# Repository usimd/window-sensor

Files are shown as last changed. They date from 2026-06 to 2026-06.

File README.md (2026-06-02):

# BLE window sensor for Homeassistant







BLE window/door sensor built around the u-blox NORA-B226 (nRF54L10). Broadcasts open/closed/tilt state via BTHome v2 non-connectable advertising. MCUboot OTA-capable.

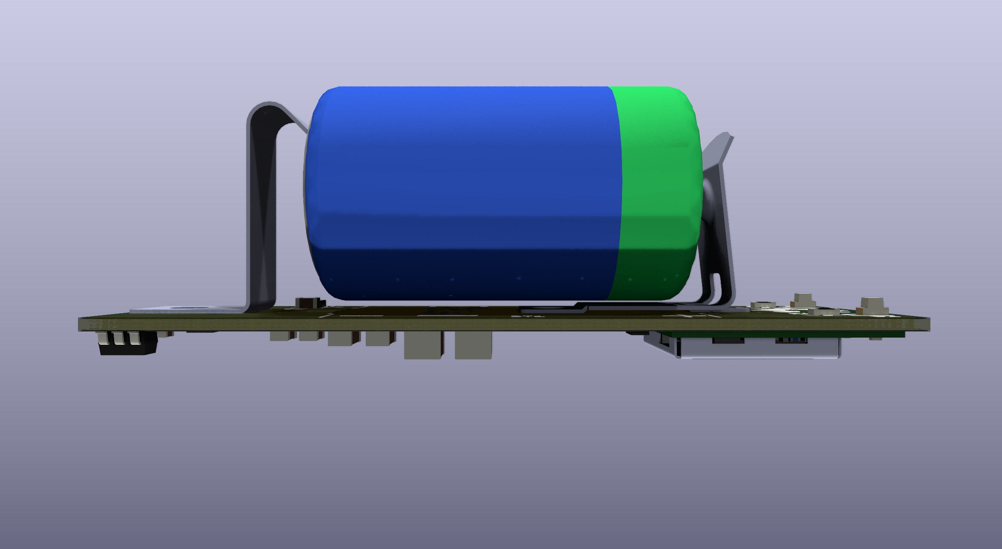
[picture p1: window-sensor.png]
Rendered PCB


## Hardware

- **MCU**: nRF54L10 (Cortex-M33, 1 MiB RRAM, 192 KB RAM) in u-blox NORA-B226-00B module
- **Sensor**: TMAG5273 3D Hall-effect sensor for contactless magnet detection
- **Power**: CR14250 (½AA) lithium cell, target multi-year battery life
- **Enclosure**: 3D-printed case with magnet holder (FreeCAD, `case/`)

## Firmware

Rust + Embassy async runtime, BLE via nrf-sdc + trouble-host.

- Non-connectable BTHome v2 advertising (open / closed / tilt)
- MCUboot bootloader with ed25519-signed OTA images
- Host-side unit tests for classifier and gesture logic

## Repository Structure

| Path | Description |
|---|---|
| `*.kicad_*` | KiCad 10 schematic, PCB, and project files |
| `lib/` | Local symbol/footprint libraries and 3D models |
| `firmware/` | Rust firmware (Embassy, BLE, MCUboot support) |
| `firmware/mcuboot/` | MCUboot config and partition overlay |
| `case/` | FreeCAD enclosure design and 3MF exports |
| `scripts/` | BLE scanner and dev utilities |
| `sim/` | Magnetic simulation data |

## Building

```bash
# Install toolchain
rustup target add thumbv8m.main-none-eabihf
cargo install just cargo-binutils

# Build, lint, test
just ci

# Flash (requires probe-rs + debug probe)
just run
```

## License

Dual-licensed: hardware under CERN-OHL-W-2.0, firmware under Apache-2.0. See [`LICENSE`](LICENSE).

## AISLER discount

In case you want to build this (or any other) project at AISLER, here's a 10€ discount code for you: `MakeInEurope-ZDCTN`.

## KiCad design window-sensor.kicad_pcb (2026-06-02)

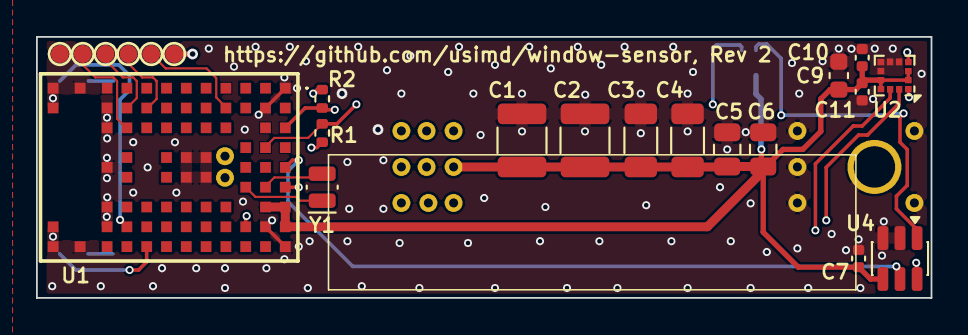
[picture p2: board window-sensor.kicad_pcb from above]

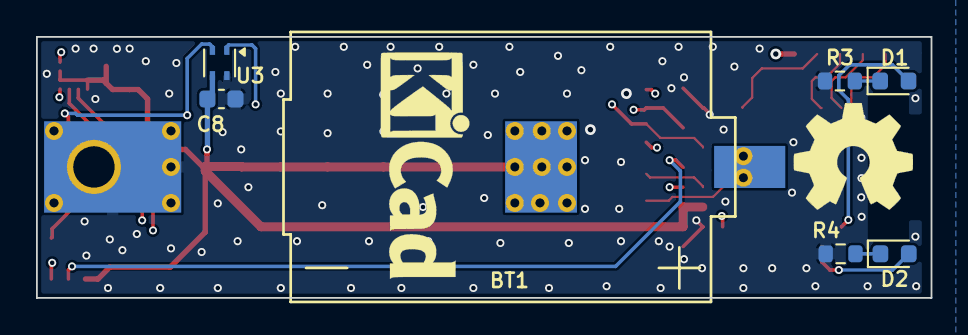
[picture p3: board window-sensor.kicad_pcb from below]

Board: 4 copper layers, 49.7 x 14.5 mm, 24 parts (7 on the bottom side), 17 nets.

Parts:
BT1: 1/2 AA LiSOCl2 3.6V 1200mAh; Battery_0.5AA_Keystone_557_5331
C1, C2: 47uF 10V X7R; C_1210_3225Metric
C3, C4: 22uF 10V X7R; C_1206_3216Metric
C5, C6: 10uF 10V X7R; C_0805_2012Metric
C7, C10, C11: 1uF; C_0402_1005Metric
C8: 1uF; C_0603_1608Metric
C9: 10uF; C_0603_1608Metric
D1: Blue; LED_0603_1608Metric
D2: Red; LED_0603_1608Metric
J1: Conn_01x06; Conn_01x06_PogoPins_1.27mm
R1, R2: 16.9k; R_0402_1005Metric
R3: 60.4; R_0603_1608Metric
R4: 160; R_0603_1608Metric
U1: NORA-B216-00B; NORAB22600B
U2: LIS2DTW12TR; LGA-12_2x2mm_P0.5mm
U3: SHT4x; Sensirion_DFN-4_1.5x1.5mm_P0.8mm_SHT4x_NoCentralPad
U4: TMAG5273; SOT-23-6
Y1: 32.768kHz; Crystal_SMD_MicroCrystal_CC8V-T1A-2Pin_2.0x1.2mm

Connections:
+BATT: BT1.1 (+), C1.1, C2.1, C3.1, C4.1, C5.1, C6.1, C7.1, C8.1, C9.1, C10.1, C11.1, J1.1, R1.1, R2.1, U1.A7 (VCC), U1.A8 (VCC_2), U1.B7 (VCC_3), U2.2 (~CS), U2.3 (SA0/SDO), U2.9 (Vdd), U2.10 (Vdd_IO), U3.3 (VDD), U4.4 (VCC)
/HALL: U1.A5 (GPIO_1), U4.5 (~INT)
/MEMS_INT1: U1.A6 (GPIO_2), U2.12 (INT1)
/MEMS_INT2: U1.C8 (GPIO_3), U2.11 (INT2)
/SCL: R2.2, U1.A3 (I2C_SCL), U2.1 (SCL/SPC), U3.2 (SCL), U4.1 (SCL)
/SDA: R1.2, U1.B4 (I2C_SDA), U2.4 (SDA/SDI), U3.1 (SDA), U4.6 (SDA)
/SWCLK: J1.4, U1.J2 (SWDCLK)
/SWDIO: J1.3, U1.H2 (SWDIO)
/UART_TX: J1.2, U1.D2 (QSPI_D0)
/~RESET: J1.5, U1.J3 (RESET_N)
GND: BT1.2 (-), C1.2, C2.2, C3.2, C4.2, C5.2, C6.2, C7.2, C8.2, C9.2, C10.2, C11.2, J1.6, R3.2, R4.2, U1.A1 (GND), U1.A9 (VSS_2), U1.B2 (VSS_3), U1.B8 (VSS_4), U1.E4 (VSS_5), U1.E5 (VSS_6), U1.F4 (VSS_7), U1.F5 (VSS_8), U1.K2 (VSS_9), U1.K3 (VSS_10), U1.K5 (VSS_11), U1.K7 (VSS_12), U1.K8 (VSS_13), U1.L1 (EAGP_1), U1.L9 (EAGP_2), U1.M1 (EAGP_3), U1.M2 (EAGP_4), U1.M8 (EAGP_5), U1.M9 (EAGP_6), U2.5 (RES), U2.6 (GND), U2.7 (GND), U2.8 (GND), U3.4 (VSS), U4.2 (GND), U4.3 (TEST)
unnamed: D1.2 (A), U1.J8 (GPIO_8)
unnamed: D1.1 (K), R3.1
unnamed: D2.2 (A), U1.H9 (GPIO_7)
unnamed: D2.1 (K), R4.1
unnamed: U1.B6 (XTAL_32K_1), Y1.2
unnamed: U1.C6 (XTAL_32K_2), Y1.1

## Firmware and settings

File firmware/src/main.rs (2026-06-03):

#![no_std]
#![no_main]
#![allow(dead_code)] // Driver register constants and board type aliases are reference documentation

use bt_hci::cmd::SyncCmd;
use core::cell::RefCell;
use defmt::*;
use embassy_executor::Spawner;

use embassy_embedded_hal::shared_bus::blocking::i2c::I2cDevice;
use embassy_nrf::cracen;
use embassy_nrf::gpio::{Input, Level, Output, OutputDrive, Pull};
use embassy_nrf::nvmc;
use embassy_nrf::pac;
use embassy_nrf::saadc;
use embassy_nrf::twim::{self, Twim};
use embassy_nrf::{bind_interrupts, peripherals};
use embassy_sync::blocking_mutex::Mutex;
use embassy_sync::blocking_mutex::raw::{CriticalSectionRawMutex, NoopRawMutex};
use embassy_sync::mutex::Mutex as AsyncMutex;
use embassy_sync::signal::Signal;
use embassy_time::Timer;
use lis2dtw12::Lis2dtw12;
use lis2dtw12::interface::{I2CInterface as LisI2cInterface, SlaveAddr as LisSlaveAddr};
use nrf_sdc::mpsl::MultiprotocolServiceLayer;
use nrf_sdc::vendor::ZephyrWriteBdAddr;
use nrf_sdc::{self as sdc, mpsl};
use sht4x::Sht4x;
use static_cell::StaticCell;
use tmag5273::{DeviceVariant, Tmag5273};
use {defmt_rtt as _, panic_probe as _};

mod board;
mod drivers;
mod tasks;

use drivers::led::Led;

const POFWARN_THRESHOLD: pac::regulators::vals::Threshold = pac::regulators::vals::Threshold::V28;

fn configure_power_fail_guard() {
    pac::REGULATORS.pofcon().write(|w| {
        w.set_pof(true);
        w.set_threshold(POFWARN_THRESHOLD);
        w.set_eventdisable(pac::regulators::vals::Eventdisable::ENABLED);
    });
    pac::RRAMC.power().config().modify(|w| {
        w.set_pof(pac::rramc::vals::Pof::ABORT);
    });
}

fn log_reset_reasons() {
    let reasons = pac::RESET.resetreas().read();
    DIAGNOSTICS_STATE.lock(|state| state.borrow_mut().note_resetreas(reasons.0));
    if reasons.0 == 0 {
        info!("[BOOT] resetreas=power_on");
        return;
    }

    info!(
        "[BOOT] resetreas raw=0x{:08x} pin={} dog0={} dog1={} ctrlapsoft={} ctrlaphard={} ctrlappin={} sreq={} lockup={} off={} lpcomp={} dif={} grtc={} nfc={} sectamper={}",
        reasons.0,
        reasons.resetpin(),
        reasons.dog0(),
        reasons.dog1(),
        reasons.ctrlapsoft(),
        reasons.ctrlaphard(),
        reasons.ctrlappin(),
        reasons.sreq(),
        reasons.lockup(),
        reasons.off(),
        reasons.lpcomp(),
        reasons.dif(),
        reasons.grtc(),
        reasons.nfc(),
        reasons.sectamper(),
    );
    pac::RESET.resetreas().write(|w| *w = reasons);
}

// --- Interrupt bindings ---

bind_interrupts!(struct Irqs {
    SERIAL20 => twim::InterruptHandler<peripherals::SERIAL20>;
    SAADC => saadc::InterruptHandler;
    SWI00 => mpsl::LowPrioInterruptHandler;
    CLOCK_POWER => mpsl::ClockInterruptHandler;
    RADIO_0 => mpsl::HighPrioInterruptHandler;
    TIMER10 => mpsl::HighPrioInterruptHandler;
    GRTC_3 => mpsl::HighPrioInterruptHandler;
});

// --- Shared state ---

/// Signal from window_task -> ble_task when state changes
pub static STATE_CHANGED: Signal<CriticalSectionRawMutex, tasks::window::WindowEvent> =
    Signal::new();

/// Signal from env_task -> ble_task with environment data
pub static ENV_DATA: Signal<CriticalSectionRawMutex, window_sensor::telemetry::EnvReading> =
    Signal::new();

/// Signal from sensor tasks -> setup_task with onboarding/runtime events.
pub static SETUP_EVENT: Signal<CriticalSectionRawMutex, window_sensor::setup::SetupEvent> =
    Signal::new();

/// Latest setup state for tasks that need context-sensitive event mapping.
pub static SETUP_STATE: Mutex<CriticalSectionRawMutex, RefCell<window_sensor::setup::SetupState>> =
    Mutex::new(RefCell::new(window_sensor::setup::SetupState::FactoryNew));

/// Signal from setup_task -> future BLE/UX tasks with setup decisions.
pub static SETUP_CHANGED: Signal<CriticalSectionRawMutex, window_sensor::setup::SetupDecision> =
    Signal::new();

/// Signal from setup_task -> window_task to capture the next calibration phase.
pub static WINDOW_CALIBRATION_REQUEST: Signal<
    CriticalSectionRawMutex,
    window_sensor::setup::CalibrationPhase,
> = Signal::new();

/// Signal from setup_task -> blue LED task with the current setup hint.
pub static SETUP_LED_HINT: Signal<CriticalSectionRawMutex, window_sensor::setup::LedHint> =
    Signal::new();

/// Signal from MEMS task -> future BLE task with BTHome button events.
pub static BUTTON_EVENT: Signal<CriticalSectionRawMutex, window_sensor::bthome::ButtonEvent> =
    Signal::new();

/// Sticky runtime diagnostics for issue reporting.
pub static DIAGNOSTICS_STATE: Mutex<
    CriticalSectionRawMutex,
    RefCell<window_sensor::diagnostics::DiagnosticsState>,
> = Mutex::new(RefCell::new(
    window_sensor::diagnostics::DiagnosticsState::new(),
));

// --- I2C bus type alias ---
pub type I2cBus = Twim<'static>;
pub type SharedI2cBus = Mutex<NoopRawMutex, RefCell<I2cBus>>;
pub type SettingsFlash = Mutex<NoopRawMutex, RefCell<nvmc::Nvmc<'static>>>;

#[embassy_executor::task]
async fn mpsl_task(mpsl: &'static MultiprotocolServiceLayer<'static>) -> ! {
    mpsl.run().await
}

fn bd_addr() -> bt_hci::param::BdAddr {
    let ficr = embassy_nrf::pac::FICR;
    let high = u64::from(ficr.deviceaddr(1).read());
    let addr = (high << 32) | u64::from(ficr.deviceaddr(0).read());
    let addr = addr | 0x0000_c000_0000_0000;
    bt_hci::param::BdAddr::new(unwrap!(addr.to_le_bytes()[..6].try_into()))
}

// --- Main entry ---

#[embassy_executor::main]
async fn main(spawner: Spawner) {
    let mut config = embassy_nrf::config::Config::default();
    config.clock_speed = embassy_nrf::config::ClockSpeed::CK128;
    config.hfclk_source = embassy_nrf::config::HfclkSource::ExternalXtal;
    config.lfclk_source = embassy_nrf::config::LfclkSource::ExternalXtal;

    let p = embassy_nrf::init(config);
    info!("[BOOT] window-sensor v{}", env!("CARGO_PKG_VERSION"));
    log_reset_reasons();
    configure_power_fail_guard();

    let mpsl_p = mpsl::Peripherals::new(
        p.GRTC_CH7,
        p.GRTC_CH8,
        p.GRTC_CH9,
        p.GRTC_CH10,
        p.GRTC_CH11,
        p.TIMER10,
        p.TIMER20,
        p.TEMP,
        p.PPI10_CH0,
        p.PPI20_CH1,
        p.PPIB11_CH0,
        p.PPIB21_CH0,
    );
    let lfclk_cfg = mpsl::raw::mpsl_clock_lfclk_cfg_t {
        source: mpsl::raw::MPSL_CLOCK_LF_SRC_RC as u8,
        rc_ctiv: mpsl::raw::MPSL_RECOMMENDED_RC_CTIV as u8,
        rc_temp_ctiv: mpsl::raw::MPSL_RECOMMENDED_RC_TEMP_CTIV as u8,
        accuracy_ppm: mpsl::raw::MPSL_DEFAULT_CLOCK_ACCURACY_PPM as u16,
        skip_wait_lfclk_started: mpsl::raw::MPSL_DEFAULT_SKIP_WAIT_LFCLK_STARTED != 0,
    };
    static MPSL: StaticCell<MultiprotocolServiceLayer> = StaticCell::new();
    let mpsl = MPSL.init(unwrap!(MultiprotocolServiceLayer::new(
        mpsl_p, Irqs, lfclk_cfg
    )));
    spawner.spawn(unwrap!(mpsl_task(&*mpsl)));

    let sdc_p = sdc::Peripherals::new(
        p.PPI00_CH1,
        p.PPI00_CH3,
        p.PPI10_CH1,
        p.PPI10_CH2,
        p.PPI10_CH3,
        p.PPI10_CH4,
        p.PPI10_CH5,
        p.PPI10_CH6,
        p.PPI10_CH7,
        p.PPI10_CH8,
        p.PPI10_CH9,
        p.PPI10_CH10,
        p.PPI10_CH11,
        p.PPIB00_CH1,
        p.PPIB00_CH2,
        p.PPIB00_CH3,
        p.PPIB10_CH1,
        p.PPIB10_CH2,
        p.PPIB10_CH3,
    );
    static RNG: StaticCell<cracen::Cracen<'static, embassy_nrf::mode::Blocking>> =
        StaticCell::new();
    let rng = RNG.init(cracen::Cracen::new_blocking(p.CRACEN));
    static SDC_MEM: StaticCell<sdc::Mem<4096>> = StaticCell::new();
    static SDC: StaticCell<sdc::SoftdeviceController> = StaticCell::new();
    let sdc_builder = unwrap!(sdc::Builder::new());
    let sdc_builder = sdc_builder.support_adv().support_peripheral();
    let sdc_builder = unwrap!(sdc_builder.adv_count(1));
    let sdc_builder = unwrap!(sdc_builder.adv_buffer_cfg(31));
    let sdc = SDC.init(unwrap!(sdc_builder.build(
        sdc_p,
        rng,
        mpsl,
        SDC_MEM.init(sdc::Mem::new()),
    )));
    unwrap!(ZephyrWriteBdAddr::new(bd_addr()).exec(sdc).await);

    // --- LED boot flash (blue, 50ms) ---
    let mut led_blue = Led::new(Output::new(p.P1_08, Level::Low, OutputDrive::Standard));
    led_blue.flash_ms(50).await;

    // --- I2C bus init (100 kHz, shared between TMAG5273, LIS2DTW12, SHT4x) ---
    let mut twim_config = twim::Config::default();
    twim_config.frequency = twim::Frequency::K100;
    // External 16.9k pull-ups on SDA/SCL - no internal pull-up needed
    twim_config.sda_pullup = false;
    twim_config.scl_pullup = false;

    // TX RAM buffer for writes from flash (e.g., register address bytes)
    static TWIM_BUF: StaticCell<[u8; 16]> = StaticCell::new();
    let twim_buf = TWIM_BUF.init([0u8; 16]);
    let i2c = Twim::new(
        p.SERIAL20,
        Irqs,
        p.P1_03, // SDA (B4 on NORA-B216)
        p.P1_02, // SCL (A3 on NORA-B216)
        twim_config,
        twim_buf,
    );

    // Wrap I2C in a shared bus mutex so multiple async tasks can borrow it.
    static I2C_STATIC: StaticCell<SharedI2cBus> = StaticCell::new();
    let i2c = I2C_STATIC.init(Mutex::new(RefCell::new(i2c)));

    static SAADC_STATIC: StaticCell<AsyncMutex<NoopRawMutex, saadc::Saadc<'static, 1>>> =
        StaticCell::new();
    let vdd_saadc = SAADC_STATIC.init(AsyncMutex::new(tasks::environment::build_vdd_saadc(
        p.SAADC, Irqs,
    )));

    static SETTINGS_FLASH_STATIC: StaticCell<SettingsFlash> = StaticCell::new();
    let settings_flash =
        SETTINGS_FLASH_STATIC.init(Mutex::new(RefCell::new(nvmc::Nvmc::new(p.RRAMC))));
    let has_window_calibration = settings_flash.lock(|flash| {
        window_sensor::settings::load_soc_settings(&mut *flash.borrow_mut())
            .unwrap_or_default()
            .window_calibrated
    });

    // --- Probe sensors ---
    info!("[INIT] Probing I2C devices...");

    // TMAG5273 WHO_AM_I
    {
        let tmag_bus = I2cDevice::new(i2c);
        match Tmag5273::detect(tmag_bus, DeviceVariant::B1.default_address()) {
            Ok(_) => info!("[INIT] TMAG5273 OK (addr=0x22)"),
            Err(_) => error!("[INIT] TMAG5273 I2C error @ 0x22"),
        }
    }

    // LIS2DTW12 WHO_AM_I
    {
        let lis_bus = LisI2cInterface::new(I2cDevice::new(i2c), LisSlaveAddr::Alternative(true));
        let mut lis = Lis2dtw12::new(lis_bus);
        match lis.get_device_id() {
            Ok(id) => {
                if id == 0x44 {
                    info!("[INIT] LIS2DTW12 OK (id=0x{:02x})", id);
                } else {
                    error!(
                        "[INIT] LIS2DTW12 unexpected id=0x{:02x} (expected 0x44)",
                        id
                    );
                }
            }
            Err(_) => error!("[INIT] LIS2DTW12 I2C error @ 0x19"),
        }
    }

    // SHT4x - no WHO_AM_I register, try serial number read
    {
        let mut sht = Sht4x::<_, embassy_time::Delay>::new(I2cDevice::new(i2c));
        let mut delay = embassy_time::Delay;
        match sht.serial_number(&mut delay) {
            Ok(serial) => info!("[INIT] SHT4x OK (serial=0x{:08x})", serial),
            Err(_) => error!("[INIT] SHT4x I2C error @ 0x44"),
        }
    }

    // --- HALL interrupt pin (active-low from TMAG5273 INT) ---
    let hall_int = Input::new(p.P1_04, Pull::Up);

    // --- MEMS interrupt pins (active-low from LIS2DTW12 INT1/INT2) ---
    let mems_int1 = Input::new(p.P1_05, Pull::Up);
    let mems_int2 = Input::new(p.P1_06, Pull::Up);

    // --- Red LED for error/tamper indication (unused for now) ---
    let _led_red = Led::new(Output::new(p.P1_10, Level::Low, OutputDrive::Standard));

    // --- Spawn tasks ---
    info!("[INIT] Spawning tasks...");

    spawner.spawn(unwrap!(tasks::setup::setup_task(has_window_calibration)));
    spawner.spawn(unwrap!(tasks::setup::setup_led_task(led_blue)));
    spawner.spawn(unwrap!(tasks::window::window_task(
        i2c,
        hall_int,
        settings_flash
    )));
    spawner.spawn(unwrap!(tasks::mems::mems_task(
        i2c,
        mems_int1,
        mems_int2,
        window_sensor::mems_tuning::mems_config(),
    )));
    spawner.spawn(unwrap!(tasks::environment::environment_task(
        i2c,
        vdd_saadc,
        settings_flash,
        tasks::environment::EnvironmentConfig::default(),
    )));
    spawner.spawn(unwrap!(tasks::ble::ble_task(sdc)));

    info!("[INIT] System running - idle");

    loop {
        Timer::after_secs(60).await;
        trace!("[HEARTBEAT] alive");
    }
}

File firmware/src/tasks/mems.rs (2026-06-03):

use defmt::*;
use embassy_embedded_hal::shared_bus::blocking::i2c::I2cDevice;
use embassy_futures::select::{Either, select};
use embassy_nrf::gpio::Input;
use embassy_sync::blocking_mutex::raw::NoopRawMutex;
use embassy_time::{Duration, Instant, Timer};
use lis2dtw12::interface::{I2CInterface as LisI2cInterface, SlaveAddr as LisSlaveAddr};
use lis2dtw12::{
    BandwidthSelection, FullScale, Int1PadConfig, Int2PadConfig, Lis2dtw12, Mode, OutputDataRate,
    TapPriority, Threshold6D,
};

use crate::{BUTTON_EVENT, SETUP_EVENT, SETUP_STATE, SharedI2cBus};
use window_sensor::mems::{
    IdsDetector, IdsSignal, MemsConfig, MemsInterruptConfig, MemsOrientationThreshold,
    ids_enabled_for_setup_state, setup_gestures_enabled_for_state,
};
use window_sensor::mems_button::{MemsButtonDetector, MemsButtonSignal};
use window_sensor::setup::{MemsGestureDetector, MemsInterrupt, SetupEvent, SetupState};

type LisBus = I2cDevice<'static, NoopRawMutex, embassy_nrf::twim::Twim<'static>>;
type LisDevice = Lis2dtw12<LisI2cInterface<LisBus>>;

const RETRY_DELAY: Duration = Duration::from_secs(5);

#[embassy_executor::task]
pub async fn mems_task(
    bus: &'static SharedI2cBus,
    mut mems_int1: Input<'static>,
    mut mems_int2: Input<'static>,
    config: MemsConfig,
) {
    info!("[MEMS] Task started");

    let mut button_detector = MemsButtonDetector::new(config.button);
    let mut gesture_detector = MemsGestureDetector::new();
    let mut ids_detector = IdsDetector::new(config.ids);

    loop {
        let mut lis = match init_lis(bus, config.interrupts) {
            Ok(lis) => {
                info!("[MEMS] LIS2DTW12 configured for interrupts");
                lis
            }
            Err(_) => {
                error!("[MEMS] Failed to initialize LIS2DTW12 interrupts");
                Timer::after(RETRY_DELAY).await;
                continue;
            }
        };

        loop {
            let now_ms = Instant::now().as_millis();
            match next_button_deadline_ms(&button_detector, now_ms) {
                Some(deadline_ms) if deadline_ms <= now_ms => {
                    flush_button_tick(&mut button_detector, now_ms);
                    continue;
                }
                Some(deadline_ms) => {
                    let wait_ms = deadline_ms.saturating_sub(now_ms);
                    match select(
                        select(mems_int1.wait_for_low(), mems_int2.wait_for_low()),
                        Timer::after_millis(wait_ms),
                    )
                    .await
                    {
                        Either::First(Either::First(_)) => {
                            if handle_interrupt(
                                &mut lis,
                                MemsLine::Int1,
                                &mut gesture_detector,
                                &mut ids_detector,
                                &mut button_detector,
                            )
                            .is_err()
                            {
                                error!("[MEMS] INT1 handling failed");
                                break;
                            }
                        }
                        Either::First(Either::Second(_)) => {
                            if handle_interrupt(
                                &mut lis,
                                MemsLine::Int2,
                                &mut gesture_detector,
                                &mut ids_detector,
                                &mut button_detector,
                            )
                            .is_err()
                            {
                                error!("[MEMS] INT2 handling failed");
                                break;
                            }
                        }
                        Either::Second(_) => flush_button_tick(&mut button_detector, deadline_ms),
                    }
                }
                None => match select(mems_int1.wait_for_low(), mems_int2.wait_for_low()).await {
                    Either::First(_) => {
                        if handle_interrupt(
                            &mut lis,
                            MemsLine::Int1,
                            &mut gesture_detector,
                            &mut ids_detector,
                            &mut button_detector,
                        )
                        .is_err()
                        {
                            error!("[MEMS] INT1 handling failed");
                            break;
                        }
                    }
                    Either::Second(_) => {
                        if handle_interrupt(
                            &mut lis,
                            MemsLine::Int2,
                            &mut gesture_detector,
                            &mut ids_detector,
                            &mut button_detector,
                        )
                        .is_err()
                        {
                            error!("[MEMS] INT2 handling failed");
                            break;
                        }
                    }
                },
            }
        }

        Timer::after(RETRY_DELAY).await;
    }
}

#[derive(Clone, Copy)]
enum MemsLine {
    Int1,
    Int2,
}
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

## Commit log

2026-06-01 Initial commit: PCB, firmware, CI pipelines
    - KiCad 9 schematic + PCB (nRF54L10 / NORA-B226-00B)
    - Custom footprints + STEP models with attribution
    - Embassy/Rust firmware (BTHome v2, MCUboot OTA)
    - CI: build/test/lint + release workflow with image signing
    - Dual license: CERN-OHL-W-2.0 (hardware) + Apache-2.0 (firmware)
    [window-sensor.kicad_pcb, window-sensor.kicad_sch]
2026-06-01 fix(ci): use kicad/kicad:10.0 container + fix cargo fmt
    - Schematic is KiCad 10 format, sparkengineering/kicad-action@v4 ships KiCad 9
    - Replace action with direct kicad-cli commands in kicad/kicad:10.0 container
    - Fix formatting in mems.rs (long assert_eq line)
    [mems.rs]
2026-06-01 fix(ci): docker run for kicad, --no-sysbuild for mcuboot
    - KiCad: container: directive breaks actions/checkout permissions;
    use docker run with volume mount instead
    - MCUboot: nRF Connect SDK v2.9.0 defaults to sysbuild which wraps
    MCUboot in multi-image build; --no-sysbuild builds bootloader standalone
2026-06-01 refactor(ci): use just recipes, bump NCS to v3.3.0, fix permissions
    - CI firmware job now calls 'just ci' + 'just sign' — same as local dev
    - KiCad docker: add --user to fix permission denied on report files
    - MCUboot: bump nRF Connect SDK to v3.3.0 (nRF54L10 board support)
    - Fix objcopy: use rust-objcopy directly (cargo objcopy arg parsing)
    - justfile: ci recipe now includes soc-heater variants, size uses cargo-binutils
2026-06-01 fix(ci): board is nrf54l15dk/nrf54l10/cpuapp in NCS v3.3.0
    The nRF54L10 doesn't have its own DK board definition in Zephyr 4.3;
    it's targeted as a SoC variant on the nRF54L15 DK.
2026-06-01 fix(ci): just var syntax, KiCad HOME=/tmp for symbol resolution
    - just variable overrides go BEFORE recipe name, not after
    - KiCad container needs HOME=/tmp so it can write .config/kicad/
    and resolve project sym-lib-table (fixes 66 phantom ERC violations)
2026-06-01 fix(ci): absolute paths for objcopy, root user for KiCad, Zephyr SDK
    - justfile objcopy: use justfile_directory() for absolute paths (fixes
    'No such file' on CI where cwd may differ)
    - KiCad docker: use --user 0:0 (root can write reports AND access
    /usr/share/kicad/template/sym-lib-table for standard symbols)
    - Release: install Zephyr SDK v0.17.0 (arm-zephyr-eabi toolchain)
    - Release: fix cargo objcopy → rust-objcopy (same arg-parsing fix)
2026-06-01 fix(ci): track .cargo/config.toml, fix KiCad sym-lib resolution
    - Add firmware/.cargo/config.toml to git (was untracked, causing cargo
    to build for x86_64 host instead of thumbv8m.main-none-eabihf on CI)
    - Copy global sym-lib-table into root's config in Docker containers so
    kicad-cli resolves standard symbol libraries when running as --user 0:0
    - Fix partitions.overlay: use &cpuapp_rram (nRF54L RRAM) instead of
    undefined &flash0 node label
2026-06-01 fix(ci): drop --user 0:0 for KiCad, fix imgtool version format
    - Run kicad-cli as default 'kicad' user (correct lib resolution),
    pre-chmod workspace for write access
    - Remove prerelease segment from imgtool versions: imgtool only
    accepts maj.min.rev[+build], not semver prerelease like -ci or -dev
2026-06-01 fix(ci): numeric imgtool version, delete-node in overlay
    - imgtool --version requires numeric build number, not hex git hash;
    use git rev-list --count HEAD instead of git rev-parse --short HEAD
    - Delete board's default partitions node before redefining to avoid
    duplicate DTS label errors (slot1_partition at two addresses)
2026-06-01 fix(ci): add pyelftools for MCUboot, ERC continue-on-error
    - MCUboot build needs pyelftools (elftools module) for post-processing
    - ERC step: continue-on-error while 3 real schematic violations exist
2026-06-01 chore: add Renovate config, track nRF Connect SDK version
    Same base config as sibling repos (monthly, automerge non-major, dashboard
    approval for major). Custom regex manager tracks NCS_VERSION against
    nrfconnect/sdk-nrf GitHub releases.
2026-06-01 Finalize PCB before fab
    [window-sensor.kicad_pcb]
2026-06-01 docs: proper README with badges, add codecov coverage
    - Board render header, AISLER fab link, CI and codecov badges
    - cargo-llvm-cov for LCOV coverage, uploaded via codecov-action
2026-06-01 ci: integrate coverage into test flow, add integration tests
    - Replace separate 'Test with coverage' step with 'just test-cov'
    - Drop --lib from test recipes to include integration tests
    - Add firmware/tests/bthome_decode.rs integration test
2026-06-02 Update docs, renovate and Rust build
    [window-sensor.kicad_pcb]
2026-06-03 refactor(firmware): make main.rs embedded entrypoint
    - move embedded runtime entry into firmware/src/main.rs
    - remove main_embedded.rs indirection
    - gate binary with embedded-bin feature for host test isolation
    - update just recipes to pass embedded-bin only for embedded flows
    - ignore reference firmware/memory.x and rely on generated linker script
    - remove stale build.rs rerun trigger on memory.x
2026-06-03 fix(ci): restore rustfmt compliance and relax KiCad DRC gate
    - apply cargo fmt output for firmware sources
    - mark KiCad DRC step continue-on-error like ERC to avoid blocking CI on known board violations
    [main.rs, mems.rs, window.rs]
2026-06-03 fix(release): build firmware binary with embedded-bin feature
    Release build-images job must enable embedded-bin so the window-sensor
    ELF exists for objcopy/signing; also pass feature to cargo size.
2026-10-29 fix(i2c): bound TWIM transactions and recover the bus at boot
    A target holding SDA or stretching SCL hung the blocking shared bus
    forever. Wrap TWIM in TimeoutTwim (50 ms per transaction) and clock out a
    stuck target with 9 pulses plus STOP before TWIM takes the pins.
    Also align embassy's LFCLK source with MPSL (RC): with LFXO, init blocked
    forever when Y1 did not start.
2026-10-29 feat(bringup): two-stage factory test and nRF54L10 probe-rs target
    - bringup binary: per-step checks with timeouts (FICR, HFXO, LFXO load-cap
    sweep, VDD, POF, RRAM, I2C pull-ups/scan, LIS2DTW12 self-test and INT
    lines, TMAG5273 INT and magnet, SHT4x, LEDs, BLE) emitting MEAS lines.
    Without a debugger it advertises 5 s after power-on, then sleeps for the
    µA measurement.
    - scripts/factory_test.py: just factory-test top|full; prompts, BLE checks,
    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
2026-10-29 fix(image): place the MCUboot header inside the primary slot
    The app was linked at the slot start, so imgtool --pad-header put the
    0x200 header at 0xFE00 inside the bootloader partition and MCUboot found
    no image in slot 0. Link at slot + 0x800 (header size keeps the vector
    table aligned), reserve room for the swap trailer, and let cortex-m-rt
    set VTOR.
2026-10-30 feat(ota): SMP server core for MCUboot image upload
    Transport-agnostic SMP (MCUmgr) handling for what an OTA client needs:
    frame reassembly, OS echo/reset/params, image state read/write and
    resumable upload into the secondary slot with lazy page erase and
    write-size staging. Test/confirm requests write the MCUboot trailer the
    way boot_set_next()/boot_set_confirmed() do.
    Host-tested against an in-memory flash with the real partition layout;
    minicbor without alloc on target.
2026-10-30 chore(git): ignore KiCad lock files and editor local history
    KiCad *.lck files contain the local username and hostname.
2026-10-30 feat(ota): serve MCUmgr SMP over GATT in hourly update window
    - migrate BLE task to trouble-host peripheral (legacy adv, no central/ext-adv)
    - connectable 5 s window per hour, gated by battery and setup state
    - SMP service on RRAM-backed slots, reset on request
    - self-confirm running image after first successful heartbeat
2026-10-30 feat(ota): reject downgrades and publish an OTA manifest
    - SMP test/perm request fails with EBADSTATE if the secondary is older
    - release attaches window-sensor-ota.json (version, size, sha256)
2026-10-30 feat(ota): gate update windows on battery voltage under heater load
    - soc-heater on by default; the environment task publishes the measured
    loaded voltage (no modelled fallback)
    - OTA requires >= 3100 mV under ~31 mA; SoC % is too flat on Li-SOCl2
    - CI checks the no-heater variant instead
2026-10-30 feat(ota): open the update window every 6 h
    Fewer windows cut the power and attack surface; the watchdog keeps its
    2 h timeout via an hourly pet.

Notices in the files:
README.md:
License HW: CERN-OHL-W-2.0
